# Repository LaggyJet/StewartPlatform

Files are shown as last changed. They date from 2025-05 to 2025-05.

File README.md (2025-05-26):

# Stewart Platform

This repository contains all files related to the **Stewart Platform** project.

## 📁 Contents

- CAD files  
- Arduino `.ino` script  
- EAGLE files  

> ⚠️ **Note:** Some **SolidWorks** relations may be broken. Please double-check mate constraints and resolve any rebuild errors when opening the assembly.

## 🛠️ About the Stewart Platform

A Stewart Platform (also known as a hexapod) is a type of parallel robot commonly used for motion simulation, precise positioning, and vibration isolation. It uses six actuators to control the platform’s position and orientation in 3D space.

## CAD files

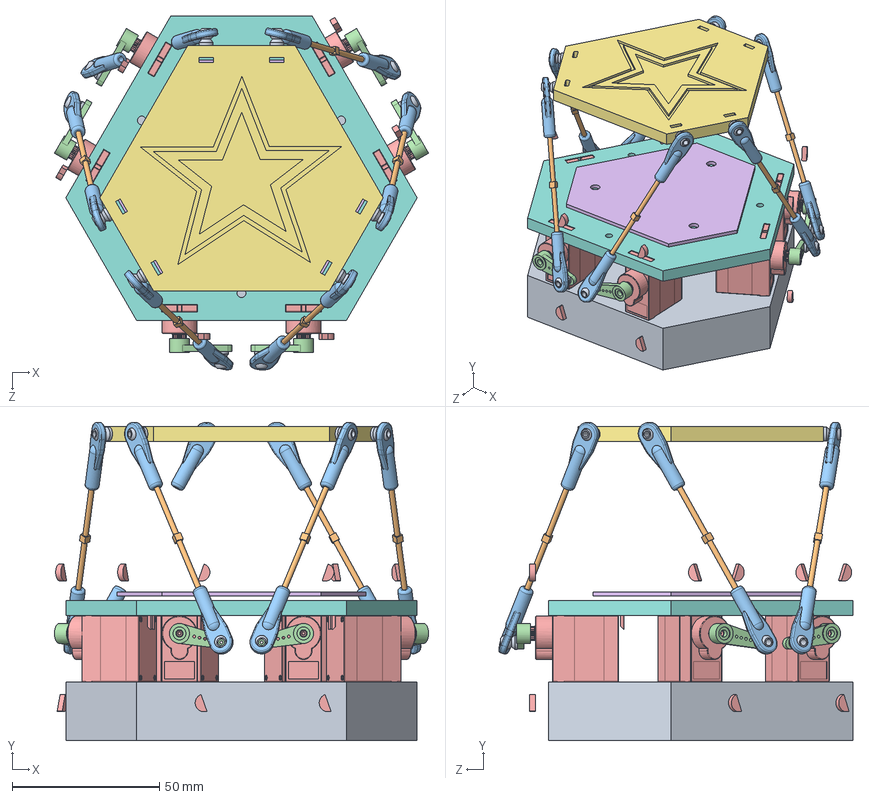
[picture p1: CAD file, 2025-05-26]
SolidWorks/JFJF-SP.SLDASM
127.0 x 108.1 x 120.1 mm
JFBottom_Plate
JFMiddle_Plate
JFTop_Plate
JFPCB
JFMG90S Micro Servo x 6
JFHorn (MG90S) x 6
JFHousing x 12
JFRod x 5
JFBalllink x 12

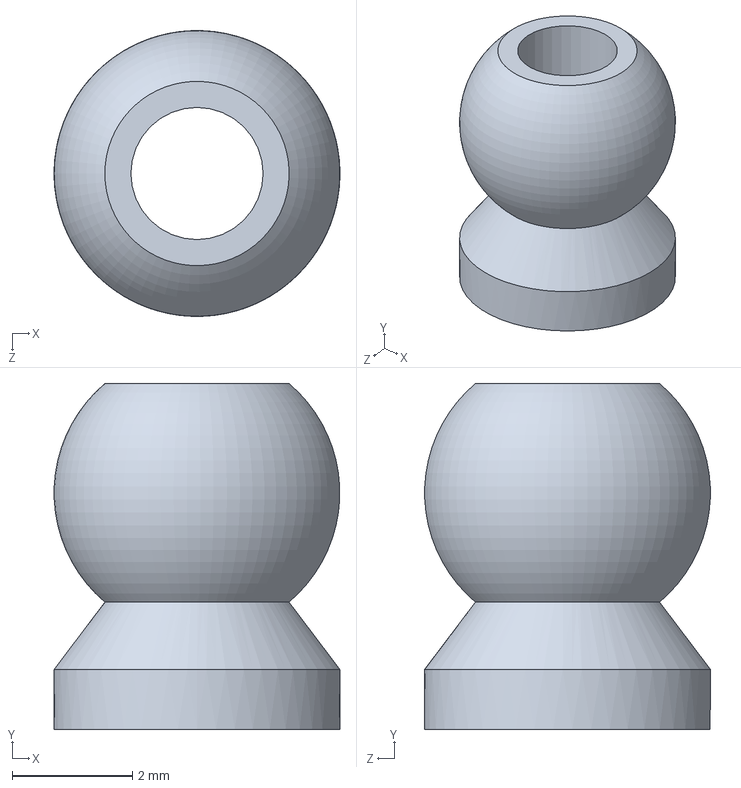
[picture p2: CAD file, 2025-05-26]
SolidWorks/JFBalllink.SLDPRT
4.76 x 5.76 x 4.76 mm

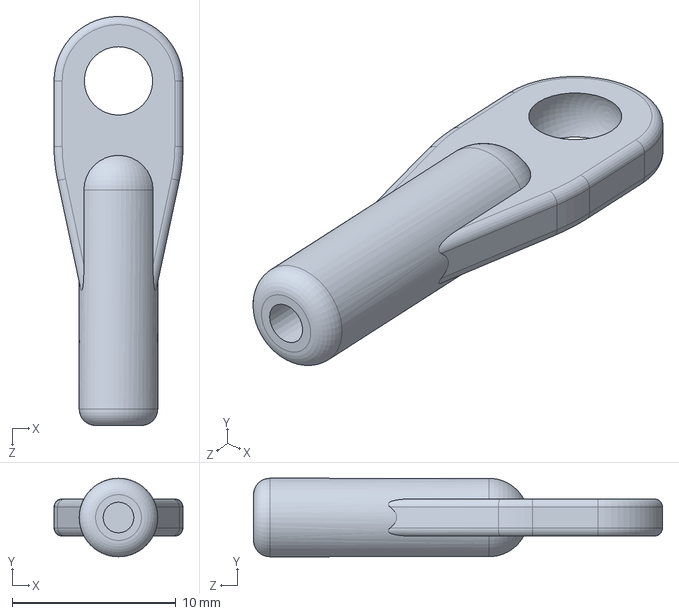
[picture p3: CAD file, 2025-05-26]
SolidWorks/JFHousing.SLDPRT
7.88 x 4.80 x 25.0 mm

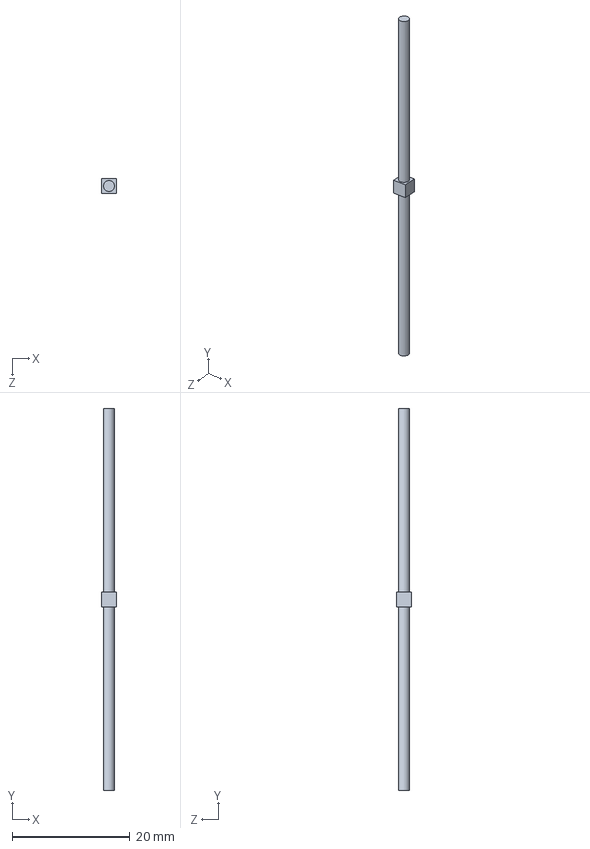
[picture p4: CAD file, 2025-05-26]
SolidWorks/JFRod.SLDPRT
2.50 x 65.0 x 2.50 mm

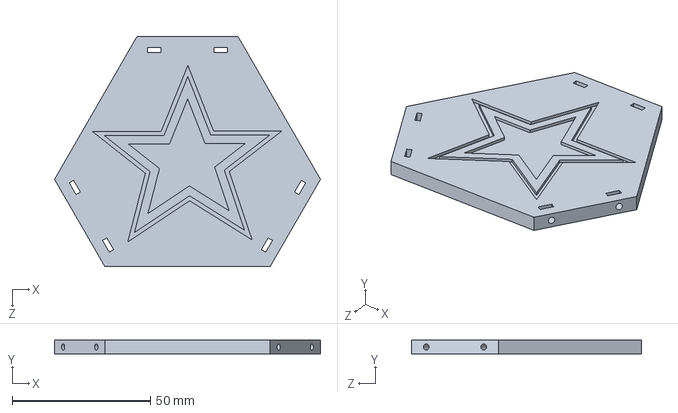
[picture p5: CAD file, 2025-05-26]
SolidWorks/JFTop_Plate.SLDPRT
96.2 x 5.00 x 83.3 mm

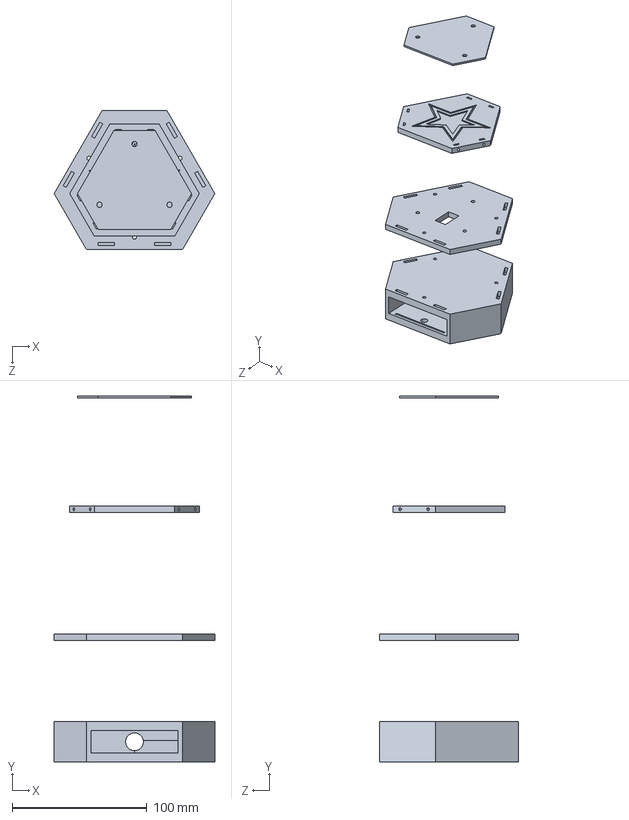
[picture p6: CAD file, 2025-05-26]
SolidWorks/JFMASTER.SLDPRT
119.2 x 271.5 x 103.3 mm

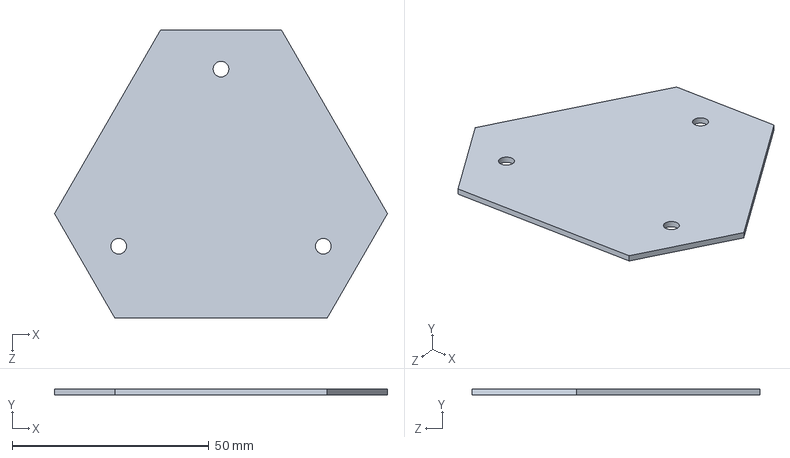
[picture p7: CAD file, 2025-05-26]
SolidWorks/JFPCB.SLDPRT
84.6 x 1.50 x 73.3 mm

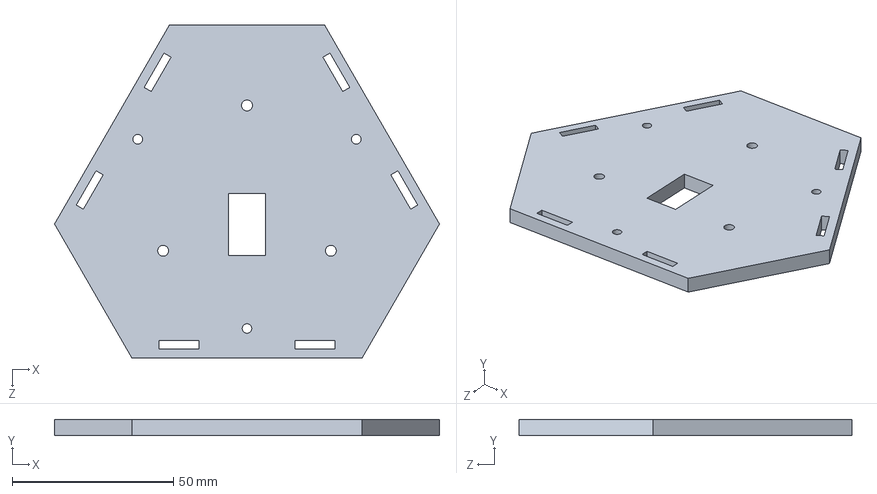
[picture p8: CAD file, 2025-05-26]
SolidWorks/JFMiddle_Plate.SLDPRT
119.2 x 5.00 x 103.3 mm

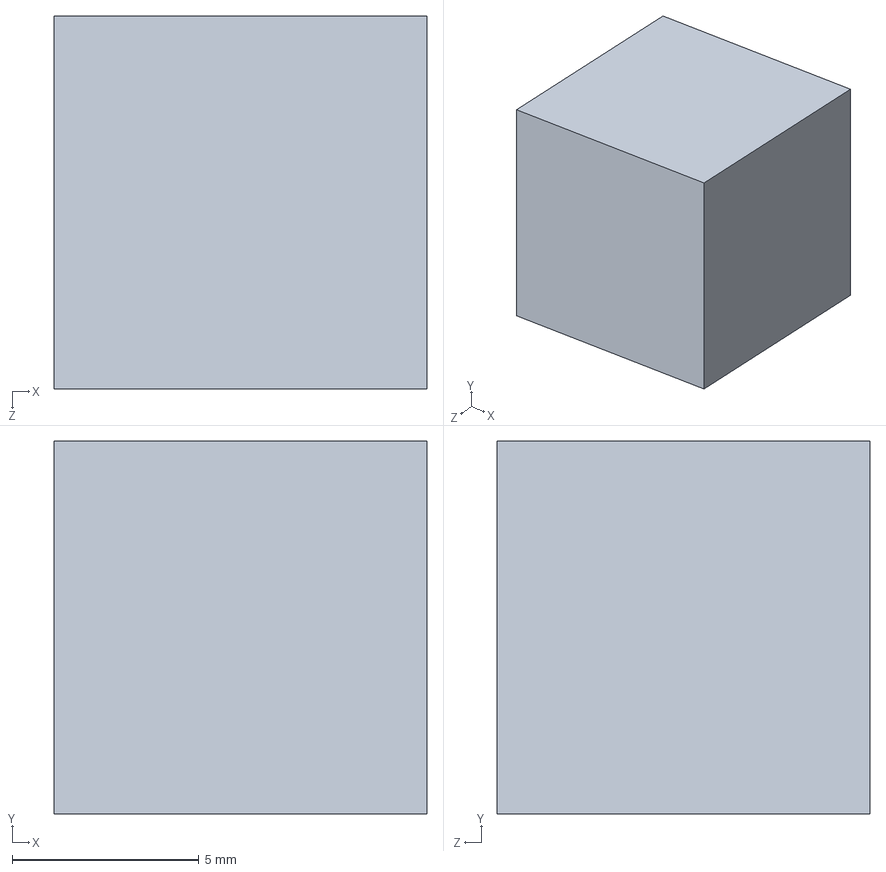
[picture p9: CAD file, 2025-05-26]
SolidWorks/JFSDOF.SLDPRT
10.0 x 10.0 x 10.0 mm

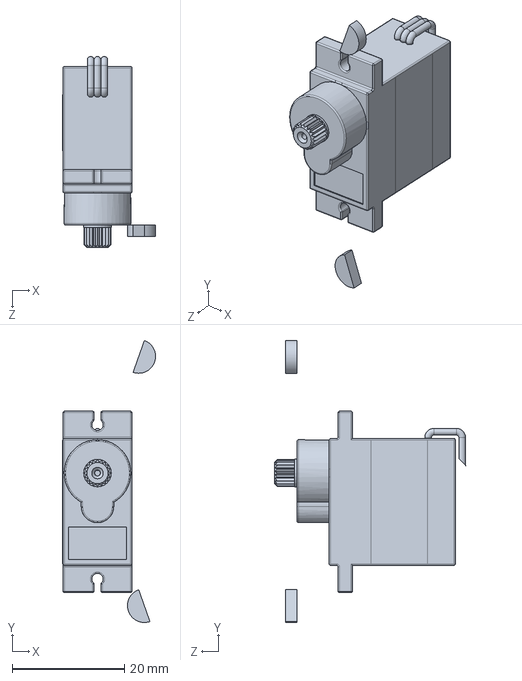
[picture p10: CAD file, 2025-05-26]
SolidWorks/JFMG90S Micro Servo.SLDPRT
16.6 x 50.1 x 34.0 mm

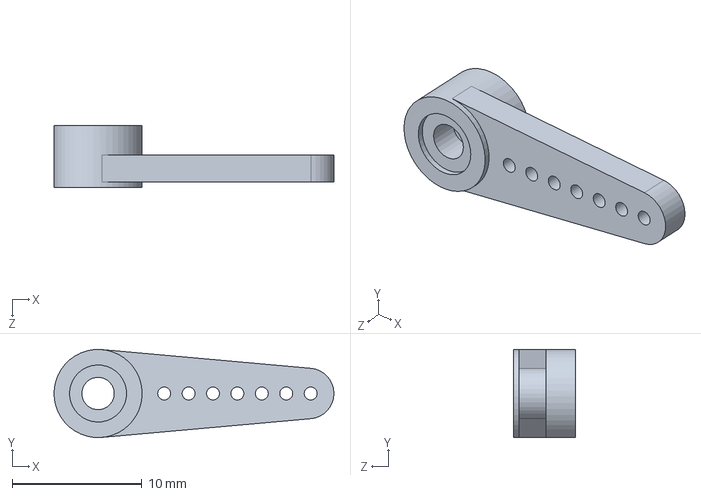
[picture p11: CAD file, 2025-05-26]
SolidWorks/JFHorn (MG90S).SLDPRT
21.6 x 6.80 x 4.75 mm

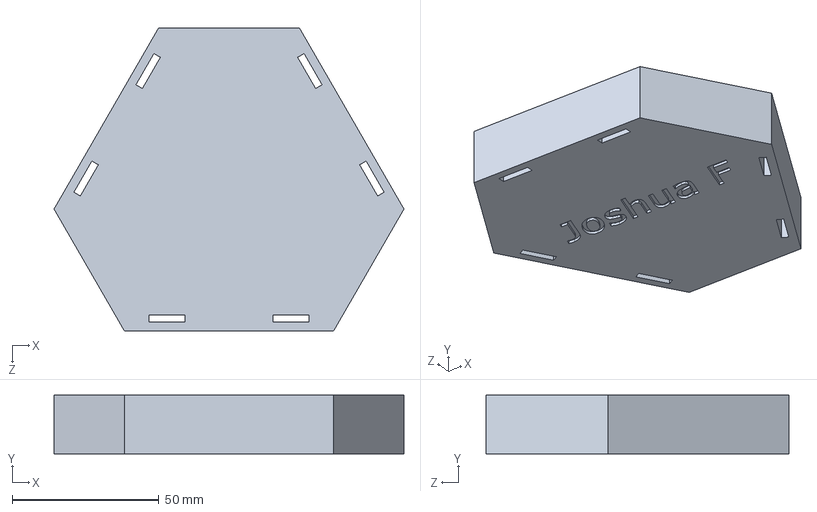
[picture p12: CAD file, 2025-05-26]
SolidWorks/JFBottom_Plate.SLDPRT
119.2 x 20.0 x 103.3 mm

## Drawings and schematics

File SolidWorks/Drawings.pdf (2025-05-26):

2

4

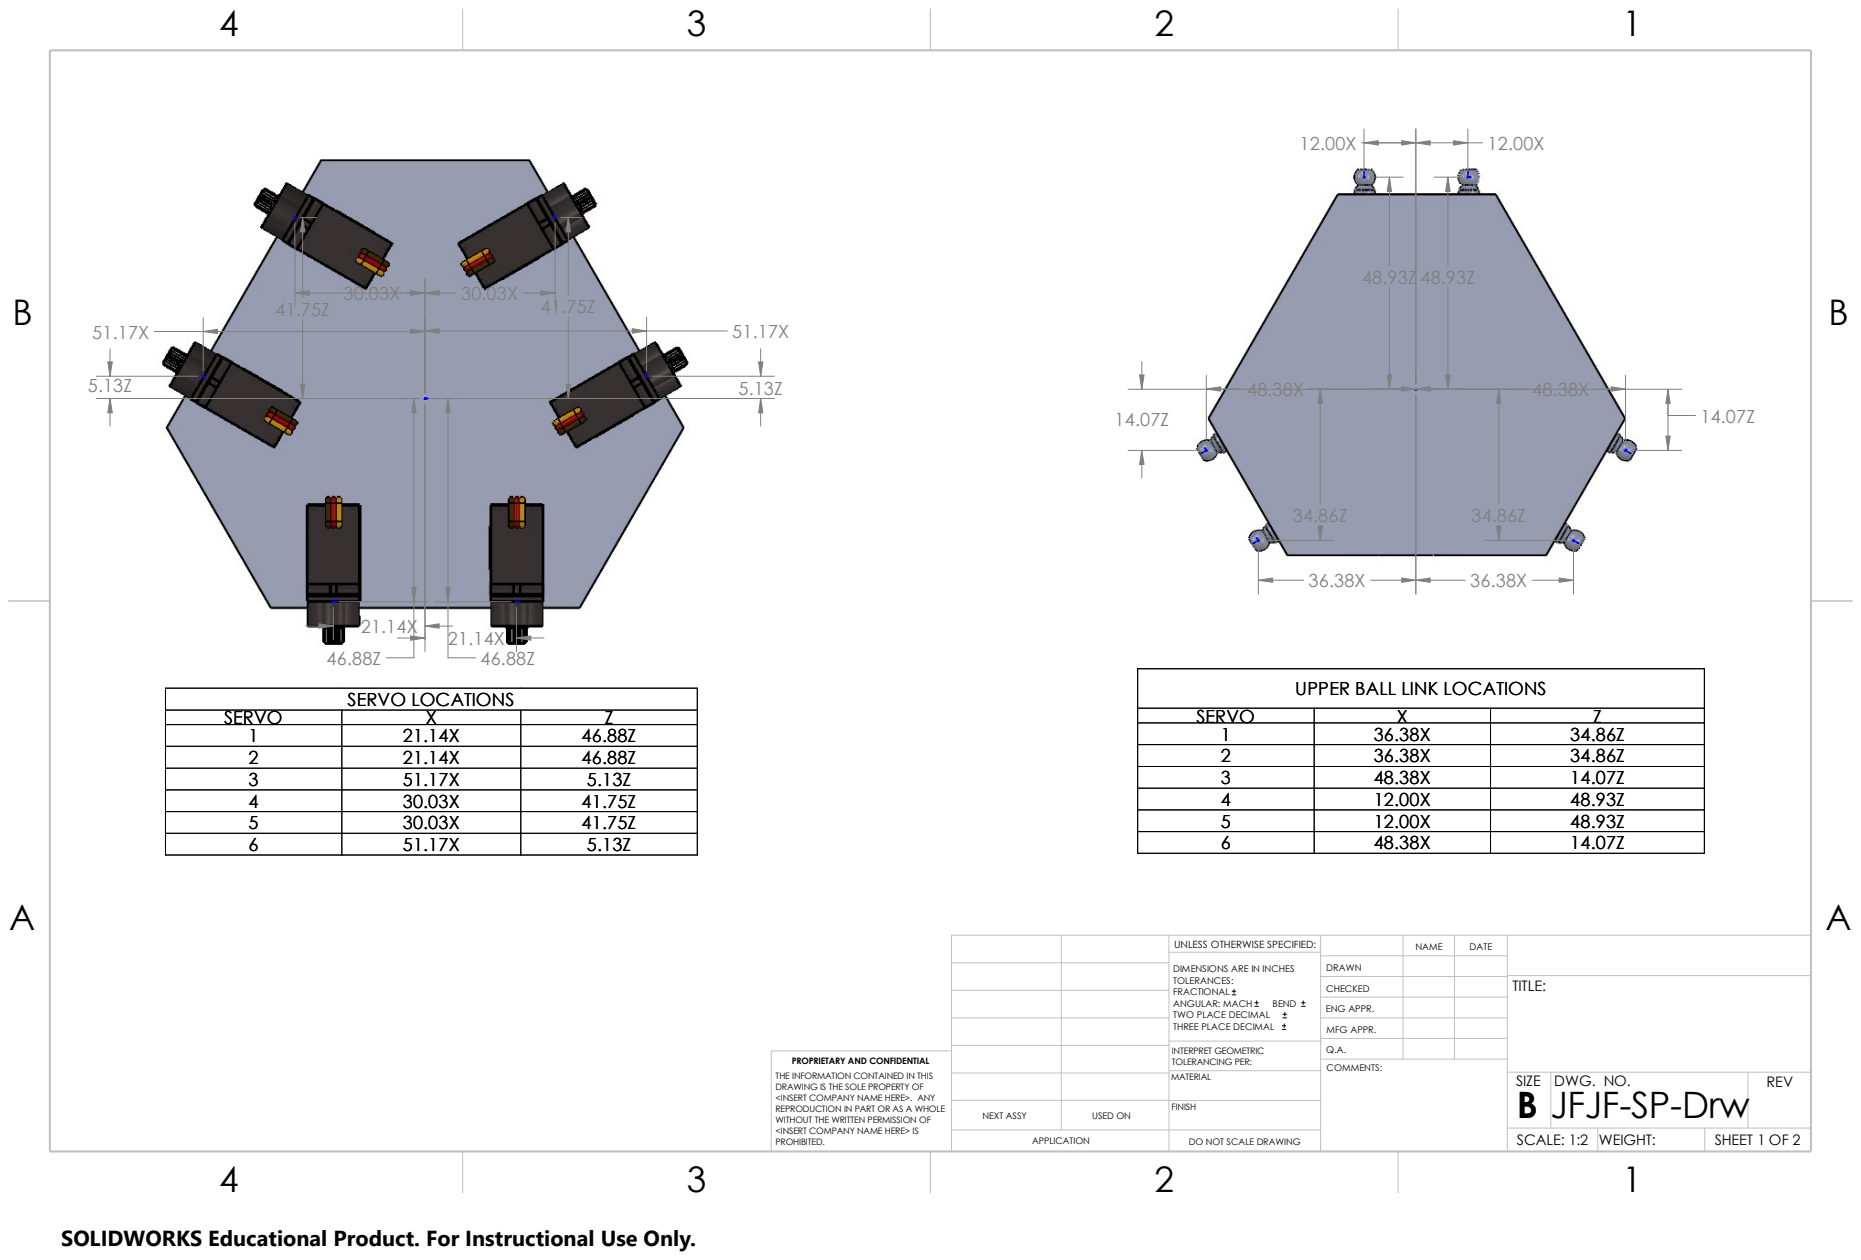
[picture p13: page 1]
COMMENTS:; BEND; SERVO LOCATIONS; SERVO

UPPER BALL LINK LOCATIONS

UNLESS OTHERWISE SPECIFIED: | | NAME | DATE

DIMENSIONS ARE IN INCHES
TOLERANCES:
FRACTIONAL
ANGULAR: MACH
TWO PLACE DECIMAL
THREE PLACE DECIMAL

DRAWN
CHECKED | | | TITLE:

ENG APPR.
MFG APPR.

INTERPRET GEOMETRIC TOLERANCING PER: | Q.A.
MATERIAL | | SIZE B | DWG. NO. JFJF-SP-Drw | REV

PROPRIETARY AND CONFIDENTIAL
THE INFORMATION CONTAINED IN THIS
DRAWING IS THE SOLE PROPERTY OF
<INSERT COMPANY NAME HERE>. ANY
REPRODUCTION IN PART OR AS A WHOLE
WITHOUT THE WRITTEN PERMISSION OF
<INSERT COMPANY NAME HERE> IS
PROHIBITED.

NEXT ASSY | USED ON | FINISH

APPLICATION | DO NOT SCALE DRAWING | | SCALE: 1:2 | WEIGHT: | SHEET 1 OF 2

SOLIDWORKS Educational Product. For Instructional Use Only.

4

3

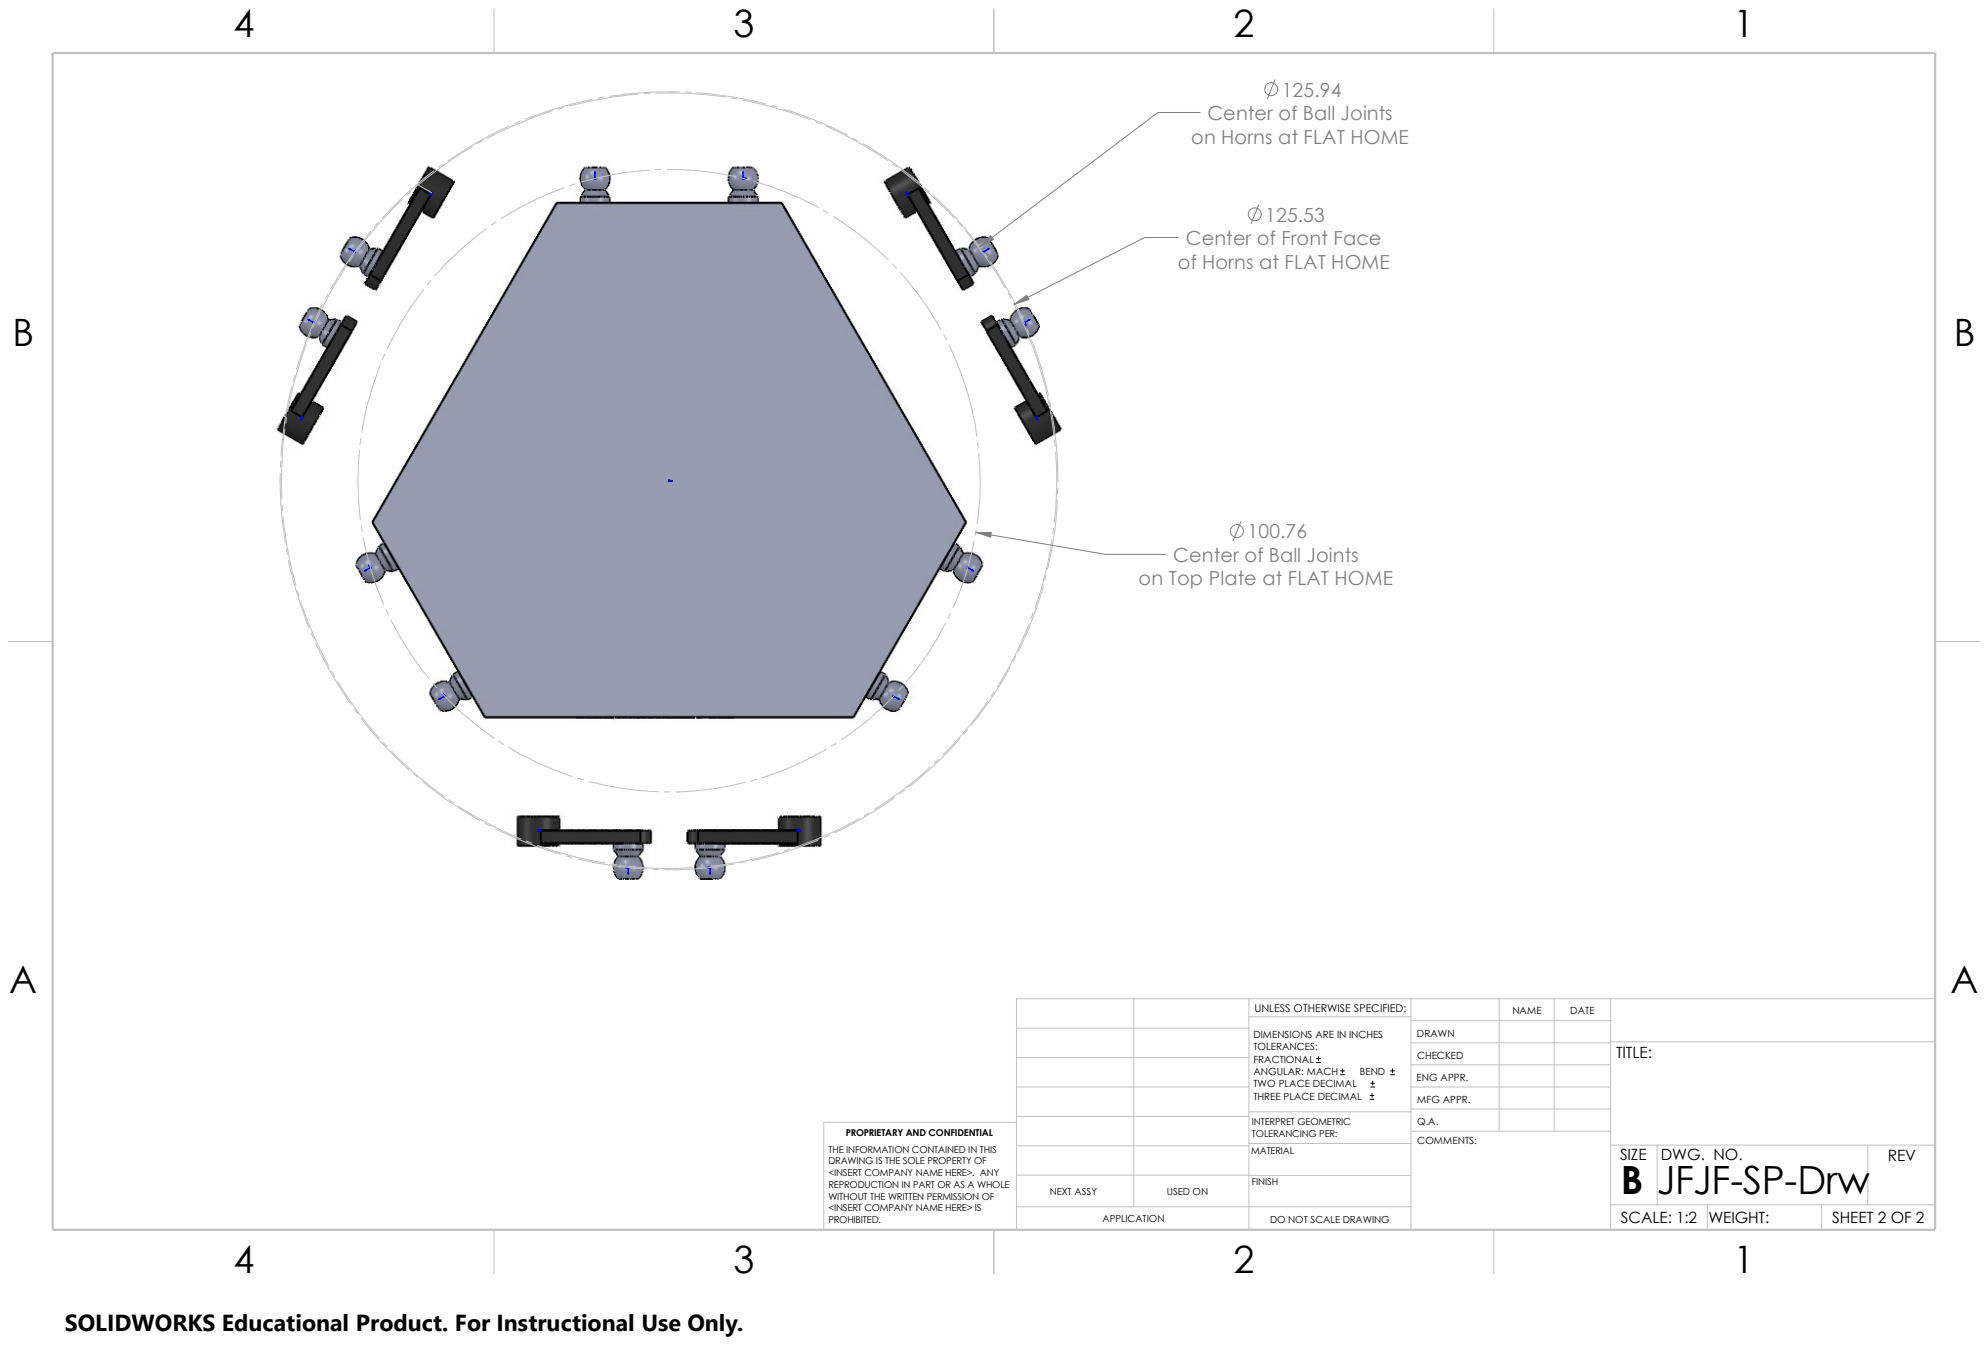
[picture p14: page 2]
COMMENTS:; BEND; INTERPRET GEOMETRIC; PROPRIETARY AND CONFIDENTIAL; TOLERANCING PER:

Center of Ball Joints
on Horns at FLAT HOME

Center of Front Face
of Horns at FLAT HOME

on Top Plate at FLAT HOME

UNLESS OTHERWISE SPECIFIED: | | NAME | DATE

DIMENSIONS ARE IN INCHES
TOLERANCES:
FRACTIONAL
ANGULAR: MACH
TWO PLACE DECIMAL
THREE PLACE DECIMAL

DRAWN
CHECKED | | | TITLE:

ENG APPR.
MFG APPR.

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

MATERIAL | | SIZE B | DWG. NO. JFJF-SP-Drw | REV

NEXT ASSY | USED ON | FINISH

APPLICATION | DO NOT SCALE DRAWING | | SCALE: 1:2 | WEIGHT: | SHEET 2 OF 2

SOLIDWORKS Educational Product. For Instructional Use Only.

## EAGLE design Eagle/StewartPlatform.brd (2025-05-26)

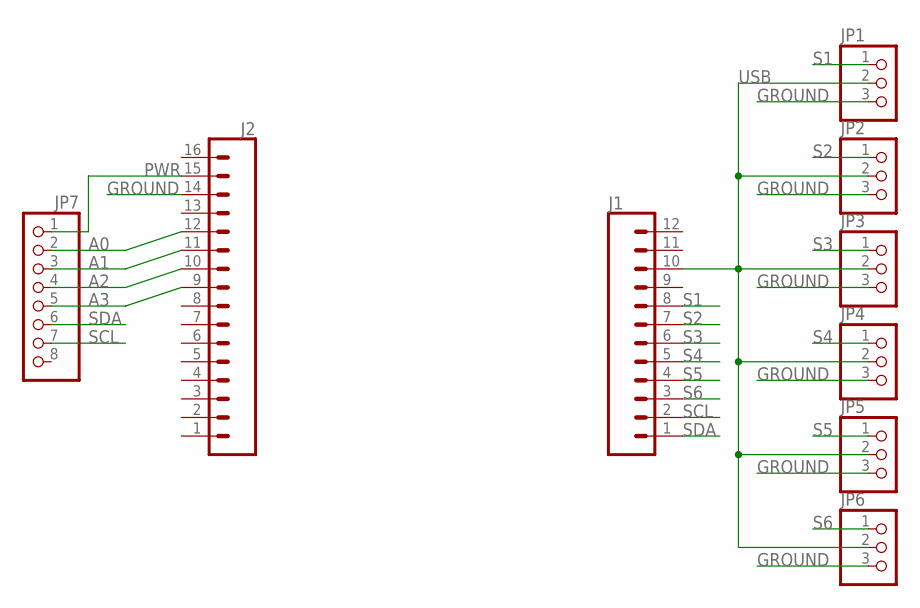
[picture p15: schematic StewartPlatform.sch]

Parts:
J1: SPARKFUN-CONNECTORS_CONN_12; SPARKFUN-CONNECTORS_1X12
J2: SPARKFUN-CONNECTORS_CONN_16; SPARKFUN-CONNECTORS_1X16
JP1, JP2, JP3, JP4, JP5, JP6: RARNDT-MISCELANEOUS_PINHD-1X3; RARNDT-MISCELANEOUS_1X03
JP7: PINHD-1X8; 1X08

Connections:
A0: J2.12, JP7.2
A1: J2.11, JP7.3
A2: J2.10, JP7.4
A3: J2.9, JP7.5
GROUND: J2.14, JP1.3, JP2.3, JP3.3, JP4.3, JP5.3, JP6.3
PWR: J2.15, JP7.1
S1: J1.8, JP1.1
S2: J1.7, JP2.1
S3: J1.6, JP3.1
S4: J1.5, JP4.1
S5: J1.4, JP5.1
S6: J1.3, JP6.1
SCL: J1.2, JP7.7
SDA: J1.1, JP7.6
USB: J1.10, JP1.2, JP2.2, JP3.2, JP4.2, JP5.2, JP6.2

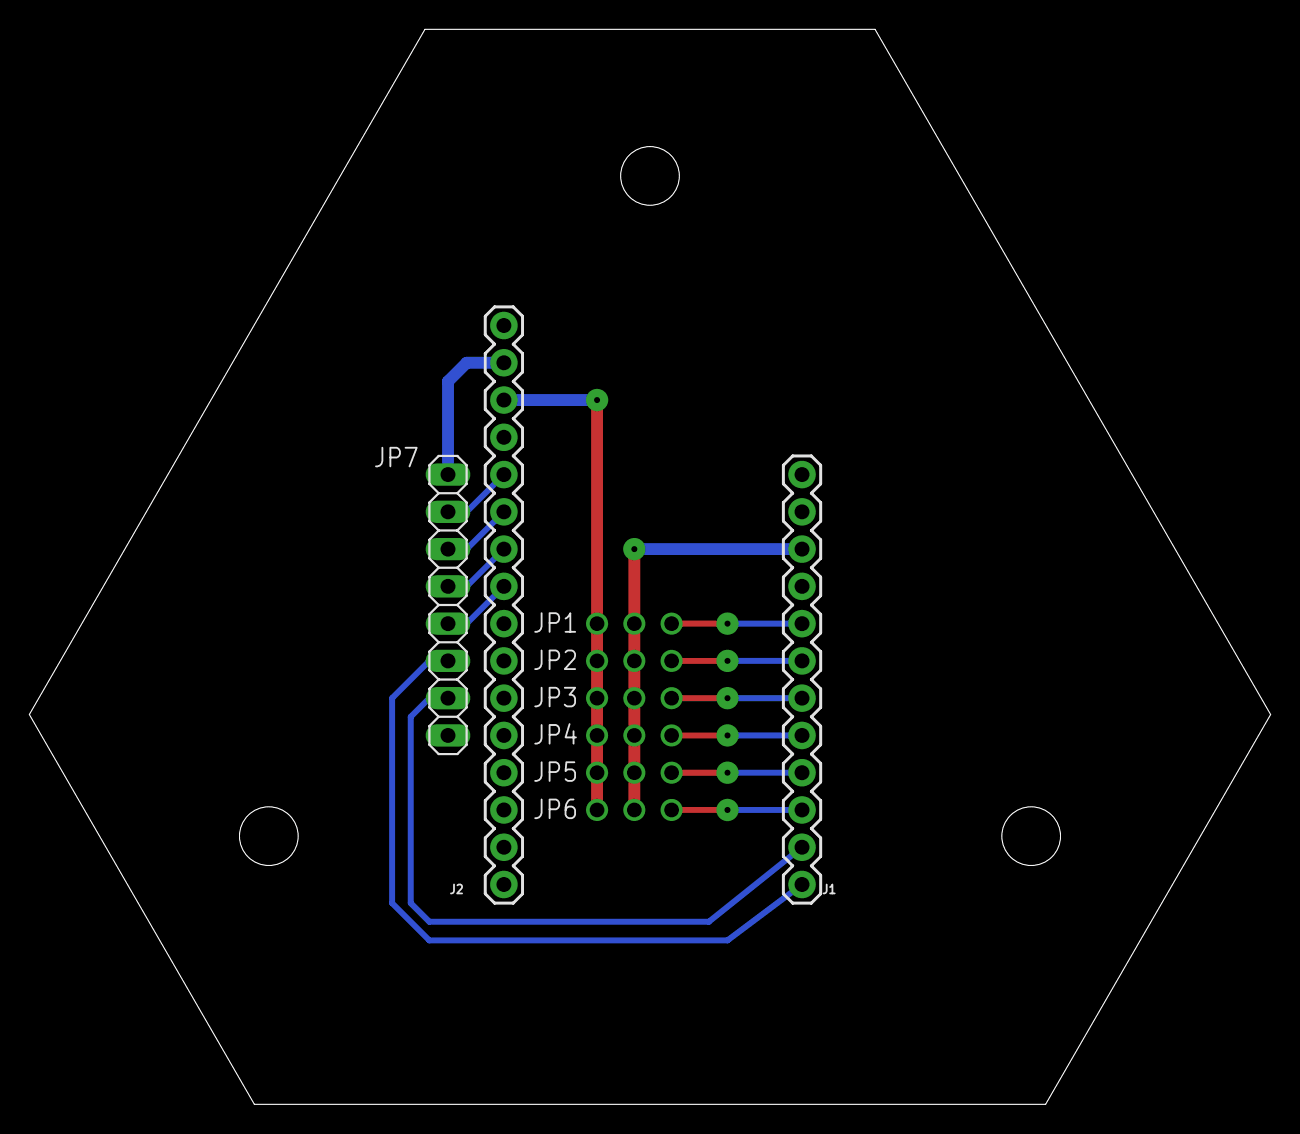
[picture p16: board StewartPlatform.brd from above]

Board: 2 copper layers, 84.6 x 73.3 mm, 9 parts (0 on the bottom side), 15 nets.

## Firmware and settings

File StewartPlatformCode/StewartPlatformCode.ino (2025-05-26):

/****
Required Arduino hardware packages:
  https://adafruit.github.io/arduino-board-index/package_adafruit_index.json
  https://espressif.github.io/arduino-esp32/package_esp32_index.json
Required Libraries:
  Arduino ESP32Servo.h
****/

#include <ESP32Servo.h>

#define NUM_SERVOS 6
#define MIN_SERVO_POS 10
#define MID_SERVO_POS 90
#define MAX_SERVO_POS 170
#define TIMESTAMP_PERIOD 500
#define NUM_PLATFORM_STATES 24

typedef struct  {
  uint8_t pin;
  int8_t trim;
  uint8_t last;
  uint8_t next;
} SERVO_DATA;

bool calibrate = false;
uint32_t timestamp = 0;
uint32_t timenow = 0;
uint8_t platform_state = 0;

// Create parameter Solidworks simulation
float platform_offset = 19.46;

Servo servos[NUM_SERVOS];

SERVO_DATA sdat[NUM_SERVOS] { 
  {12, 5, 90, 90},
  {27, -3, 90, 90},
  {33, -6, 90, 90},
  {15, -2, 90, 90},
  {32, -9, 90, 90},
  {14, 0, 90, 90} };

// Create 24x6 array of DOF platform positions from Solidworks simulation (heave, surge, sway, yaw, pitch, roll)
float platformPositions[NUM_PLATFORM_STATES][NUM_SERVOS] {
  {115.36, 64.64, 115.36, 64.64, 115.36, 64.64},
  {70.54, 109.46, 70.54, 109.46,70.54, 109.46},
  {137.25,  42.75, 137.25, 42.75, 137.25, 42.75},
  {70.54, 109.46, 70.54, 109.46,70.54, 109.46},

  {114.57, 65.43, 40.52, 89.79, 90.21, 139.48},
  {70.54, 109.46, 70.54, 109.46,70.54, 109.46},
  {51.41, 128.59, 134.52, 109.16, 70.84, 45.48},
  {70.54, 109.46, 70.54, 109.46,70.54, 109.46},

  {108.77, 129.66, 93.24, 52.49, 40.74, 109.11},
  {70.54, 109.46, 70.54, 109.46,70.54, 109.46},
  {50.57, 72.28, 70.67, 138.81, 125.39, 87.64},
  {70.54, 109.46, 70.54, 109.46,70.54, 109.46},

  {128.28, 140.74, 128.28, 140.74, 128.28, 140.74},
  {70.54, 109.46, 70.54, 109.46,70.54, 109.46},
  {39.4, 52.44, 39.4, 52.44, 39.4, 52.44},
  {70.54, 109.46, 70.54, 109.46,70.54, 109.46},

  {100.02, 79.98, 82.31, 153.6, 26.4, 97.69},
  {70.54, 109.46, 70.54, 109.46,70.54, 109.46},
  {36.37, 143.63, 53.91, 42.82, 137.18, 126.09},
  {70.54, 109.46, 70.54, 109.46,70.54, 109.46},

  {102.12, 143.95, 27.08, 101.53, 80.22, 63.03},
  {70.54, 109.46, 70.54, 109.46,70.54, 109.46},
  {36.41, 78.18, 116.39, 99.87, 62.67, 152.46},
  {70.54, 109.46, 70.54, 109.46,70.54, 109.46}
};

// Process KVP (KEY=VAL)
String procKVP(String skvp) {
  String sret;
	bool rv = true;

	if (skvp.length()) {
    skvp.toUpperCase();

		int16_t z = skvp.indexOf("=");
    if (z == -1) 
      z = skvp.length();
		String skey = skvp.substring(0, z);
		String sval = skvp.substring(z + 1);
		uint32_t ival = sval.toInt();
		float fval = sval.toFloat();

		//****************************//
		//***** sval length == 0 *****//
		//****************************//
		if (sval.length() == 0) {
      // Set calibration mode
			if (skey == "C") 
        sval = String(calibrate);

      // print trim all servos
      else if (skey == "T") {
        for (uint8_t i = 0; i < NUM_SERVOS; i++) {
          sval += " ";
          sval += String(sdat[i].trim);
        }
      }

      // Print trim specific servo
      else if (skey[0] == 'T') {
        int8_t i = skey[1] - 48;
        if ((i  < 0) || (i >= NUM_SERVOS)) 
          rv = false;
        else 
          sval = String(sdat[i].trim);
      }

      // Print offset all servos
      else if (skey == "O") 
        sval  = String(platform_offset);

      // Else error
			else 
        rv = false;
		}

		//*********************************//
		//***** else sval length != 0 *****//
		//*********************************//

    // Set calibration state
    else if (skey == "C") 
      calibrate = ival;

    // Set trim all servos
    else if (skey == "T")
      for (uint8_t i = 0; i < NUM_SERVOS; i++) 
        sdat[i].trim = ival;

    // Set trim specific servo
    else if (skey[0] == 'T') {
      int8_t i = skey[1] - 48;
      if ((i  < 0) || (i >= NUM_SERVOS)) 
        rv = false;
      else 
        sdat[i].trim = ival;
    }

    // Set offset all servos
    else if (skey == "O") 
      platform_offset = ival;

    // Else error
		else 
      rv = false;

    // If command OK
		if (rv == true) {
			if (sval.length()) 
        sret = skey + "=" + sval + " OK";
			else 
        sret = skey + " OK";
    }

    // Else command ER
    else 
      sret = skvp + " ER";

    Serial.println(sret);
	}

	return(sret);
}

// Read KVP
String readKVP(void) {
	bool rv = false;
	static uint8_t x = 0;
	static String sstr = "";

	if (x == 0) 
    sstr = "";

	while (Serial.available()) {
		char c = (char)Serial.read();
		if ((c == '\r') || (c == '\n')) {
			x = 0;
			rv = true;
			break;
		}

		x++;
		sstr += c;
	}

	return(rv ? sstr : String(""));
}

void setup() {
  Serial.begin(115200);

  for (int8_t i = 0; i < NUM_SERVOS; i++) {
      servos[i].attach(sdat[i].pin);
      servos[i].write(MID_SERVO_POS);
  }

  Serial.println("setup() complete");
}

void loop() {
  timenow = millis();
  procKVP(readKVP());

  // If calibrating servo trim
  if (calibrate) {
    for (int8_t i = 0; i < NUM_SERVOS; i++)
      // Set servo to 90 degrees plus trim, use contrain() to limit range
      servos[i].write(constrain(MID_SERVO_POS + sdat[i].trim, MIN_SERVO_POS, MAX_SERVO_POS));
    return;
  }

  // Calculate ratio of timenow to timestamp relative 500ms period
  float ratio = float(timenow - timestamp) / TIMESTAMP_PERIOD;

  for (int8_t i = 0; i < NUM_SERVOS; i++) {
    // Calculate lerped position between last and next using ratio
    float lerpPos = sdat[i].last + (sdat[i].next - sdat[i].last) * ratio;
    servos[i].write(constrain(lerpPos, MIN_SERVO_POS, MAX_SERVO_POS));
  }

	if (timenow - timestamp >= TIMESTAMP_PERIOD) {
    timestamp = timenow;
    
    // Set next platform state (0..23..etc)
    platform_state = (platform_state + 1) % NUM_PLATFORM_STATES;
    
    for (int8_t i = 0; i < NUM_SERVOS; i++) {
      sdat[i].last = sdat[i].next;
      sdat[i].next = constrain(platformPositions[platform_state][i] + sdat[i].trim, MIN_SERVO_POS, MAX_SERVO_POS);
    }
  }
}
